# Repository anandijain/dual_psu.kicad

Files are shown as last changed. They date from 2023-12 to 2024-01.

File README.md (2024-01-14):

# diy modular synth in kicad

watch the video series where i build this!

https://www.youtube.com/playlist?list=PL79kqjVnD2ENdJDDSTUD3ZMdZPhVVu8yw

- psu completed, ready to print
- vca (needs to be redone)
- vco 

# todo
- vcf 
- envelope generator

build notes

* for the m2 standoffs i got, use 1/8 in holes and use the m3x12 screws into the acryllic and there is no need to countersink 
* to mount pots to the acryllic, drill 9/32 " holes 
* for 1/4" jack sockets use 3/8" holes

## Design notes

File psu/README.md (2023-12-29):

# psu.kicad

basic +-12v dual power supply from 12vac

designed to be done diy with ferric chloride (thick traces)

## Parts
- big caps https://www.amazon.com/dp/B08KTLQLVK
- -12v regulator https://www.digikey.com/en/products/detail/stmicroelectronics/L7912CV/585997
- +12v regulator https://www.digikey.com/en/products/detail/stmicroelectronics/L7812CV/585973
- diodes https://www.amazon.com/gp/product/B07Q5FZR7X
- small caps https://www.amazon.com/gp/product/B094HRK8QX/
- copper boards https://www.amazon.com/dp/B01MCVLDDZ



00:00:00 intro/materials
00:07:30 buffing board
00:10:00 tracing 
00:26:30 etching
00:42:30 rinse
01:01:00 how to not dremel
01:22:00 drilling
01:39:55 soldering

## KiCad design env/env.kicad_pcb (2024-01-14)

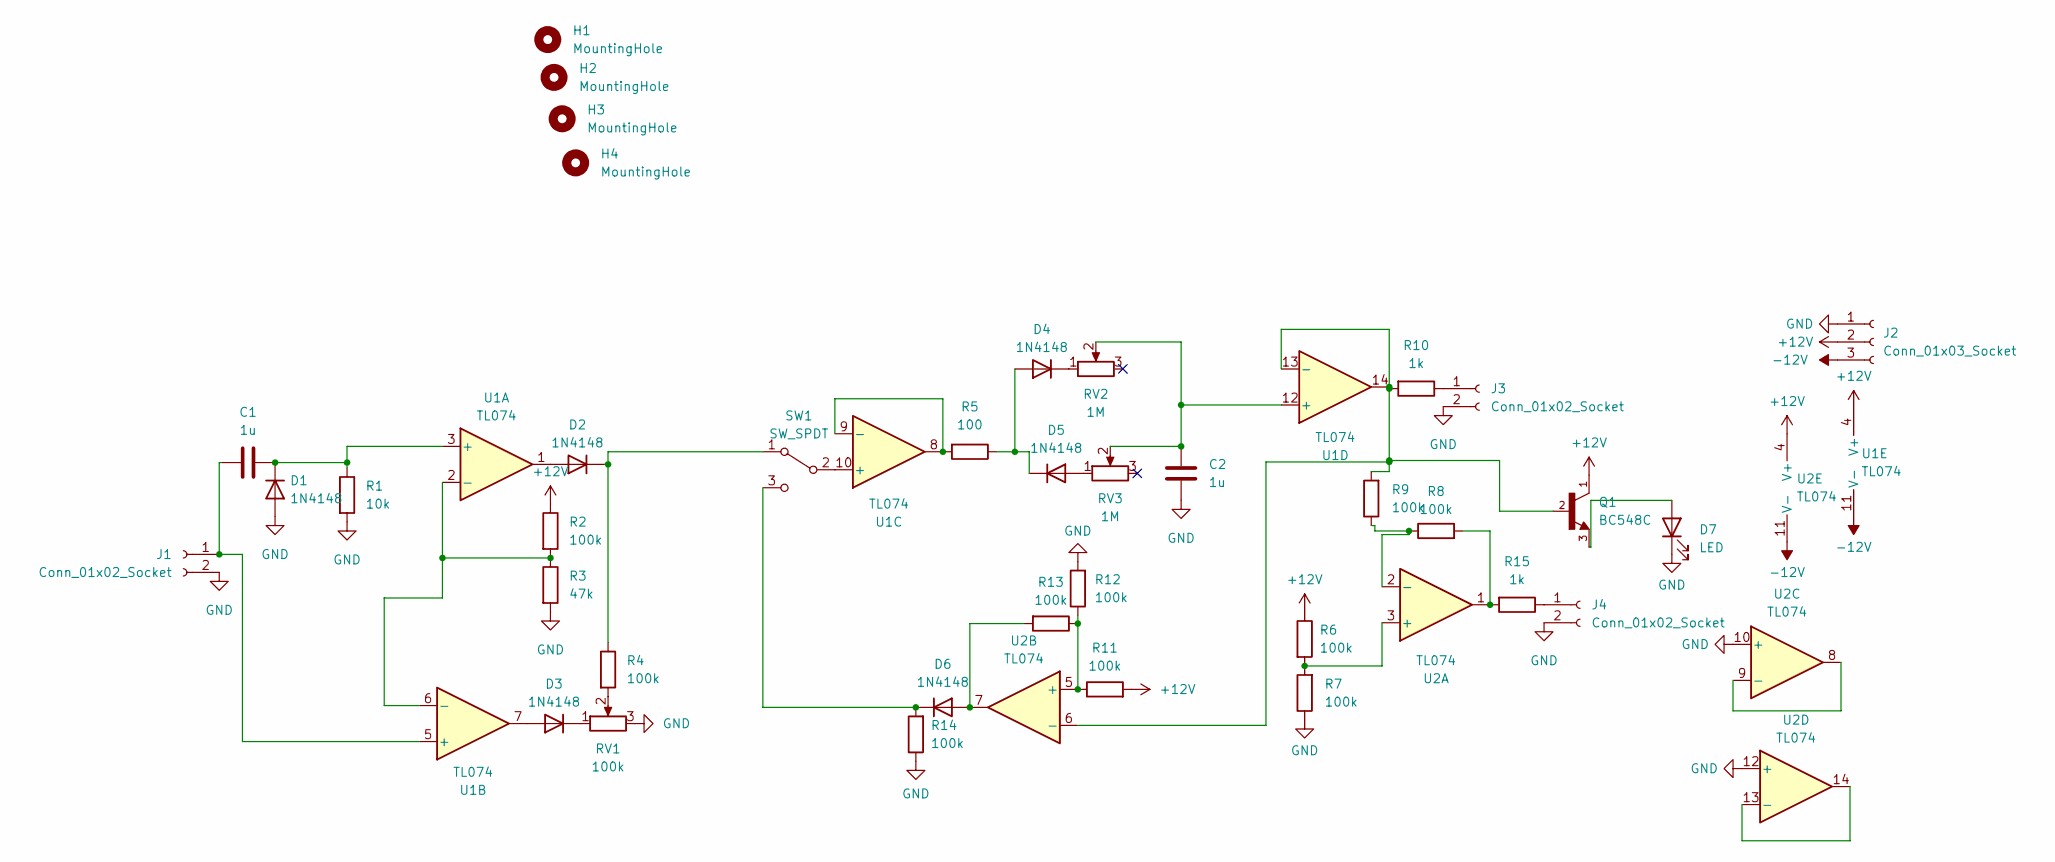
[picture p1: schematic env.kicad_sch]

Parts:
C1, C2: 1u; my_tht_cap
D1, D2, D3, D4, D5, D6: 1N4148; my_tht_diode
D7: LED; LED_D3.0mm
H1, H2, H3, H4: MountingHole; MountingHole_2.1mm
J1, J3, J4: Conn_01x02_Socket; my_really_cool_2pin
J2: Conn_01x03_Socket; my_really_cool_3pin
Q1: BC548C; my_bc548
R1: 10k; my_tht_r
R2, R4, R6, R7, R8, R9, R11, R12, R13, R14: 100k; my_tht_r
R3: 47k; my_tht_r
R5: 100; my_tht_r
R10, R15: 1k; my_tht_r
RV1: 100k; my_really_cool_3pin
RV2, RV3: 1M; my_really_cool_2pin
SW1: SW_SPDT; my_really_cool_3pin
U1, U2: TL074; my_dip14_no_f_pads

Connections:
+12V: J2.2, Q1.1, R2.1, R6.1, R11.2, U1.4 (V+), U2.4 (V+)
-12V: J2.3, U1.11 (V-), U2.11 (V-)
GND: C2.1, D1.2 (A), D7.1 (K), J1.2, J2.1, J3.2, J4.2, R1.2, R3.2, R7.1, R12.2, R14.1, RV1.3, U2.10 (+), U2.12 (+)
unnamed: C1.2, D1.1 (K), R1.1, U1.3 (+)
unnamed: D2.2 (A), U1.1
unnamed: D2.1 (K), R4.1, SW1.1 (A)
unnamed: D3.2 (A), U1.7
unnamed: D3.1 (K), RV1.1
unnamed: D4.2 (A), D5.1 (K), R5.1
unnamed: D4.1 (K), RV2.1
unnamed: D5.2 (A), RV3.1
unnamed: D6.2 (A), R13.2, U2.7
unnamed: D6.1 (K), R14.2, SW1.3 (C)
unnamed: D7.2 (A), Q1.3
unnamed: C1.1, J1.1, U1.5 (+)
unnamed: J3.1, R10.1
unnamed: J4.1, R15.1
unnamed: R4.2, RV1.2
unnamed: R8.2, R15.2, U2.1
unnamed: SW1.2 (B), U1.10 (+)
unnamed: R2.2, R3.1, U1.2 (-), U1.6 (-)
unnamed: R5.2, U1.8, U1.9 (-)
unnamed: C2.2, RV2.2, RV3.2, U1.12 (+)
unnamed: Q1.2, R9.2, R10.2, U1.13 (-), U1.14, U2.6 (-)
unnamed: R6.2, R7.2, U2.3 (+)
unnamed: R8.1, R9.1, U2.2 (-)
unnamed: R11.1, R12.1, R13.1, U2.5 (+)
unnamed: U2.8, U2.9 (-)
unnamed: U2.13 (-), U2.14

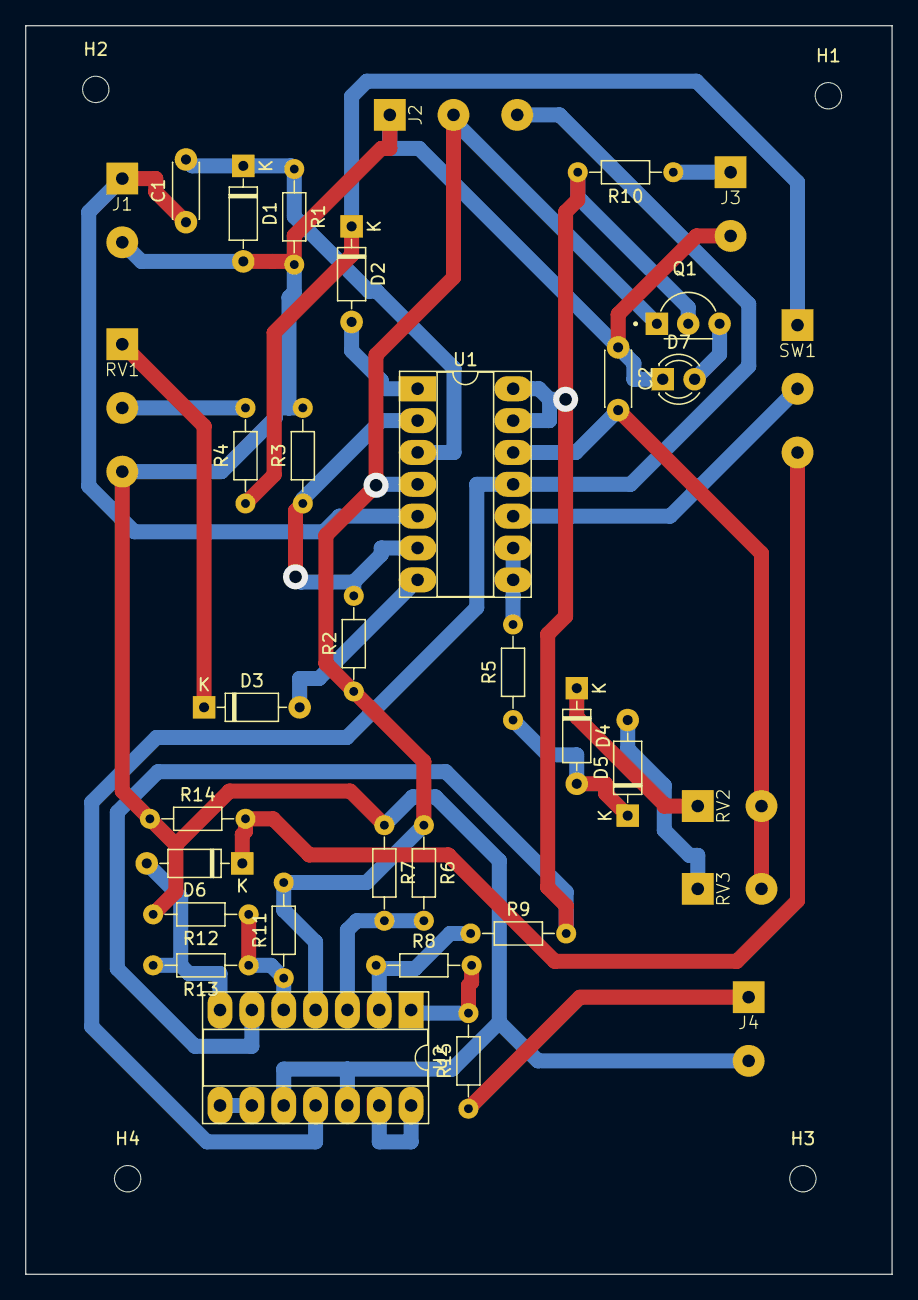
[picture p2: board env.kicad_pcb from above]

Board: 2 copper layers, 69.1 x 99.6 mm, 39 parts (0 on the bottom side), 29 nets.

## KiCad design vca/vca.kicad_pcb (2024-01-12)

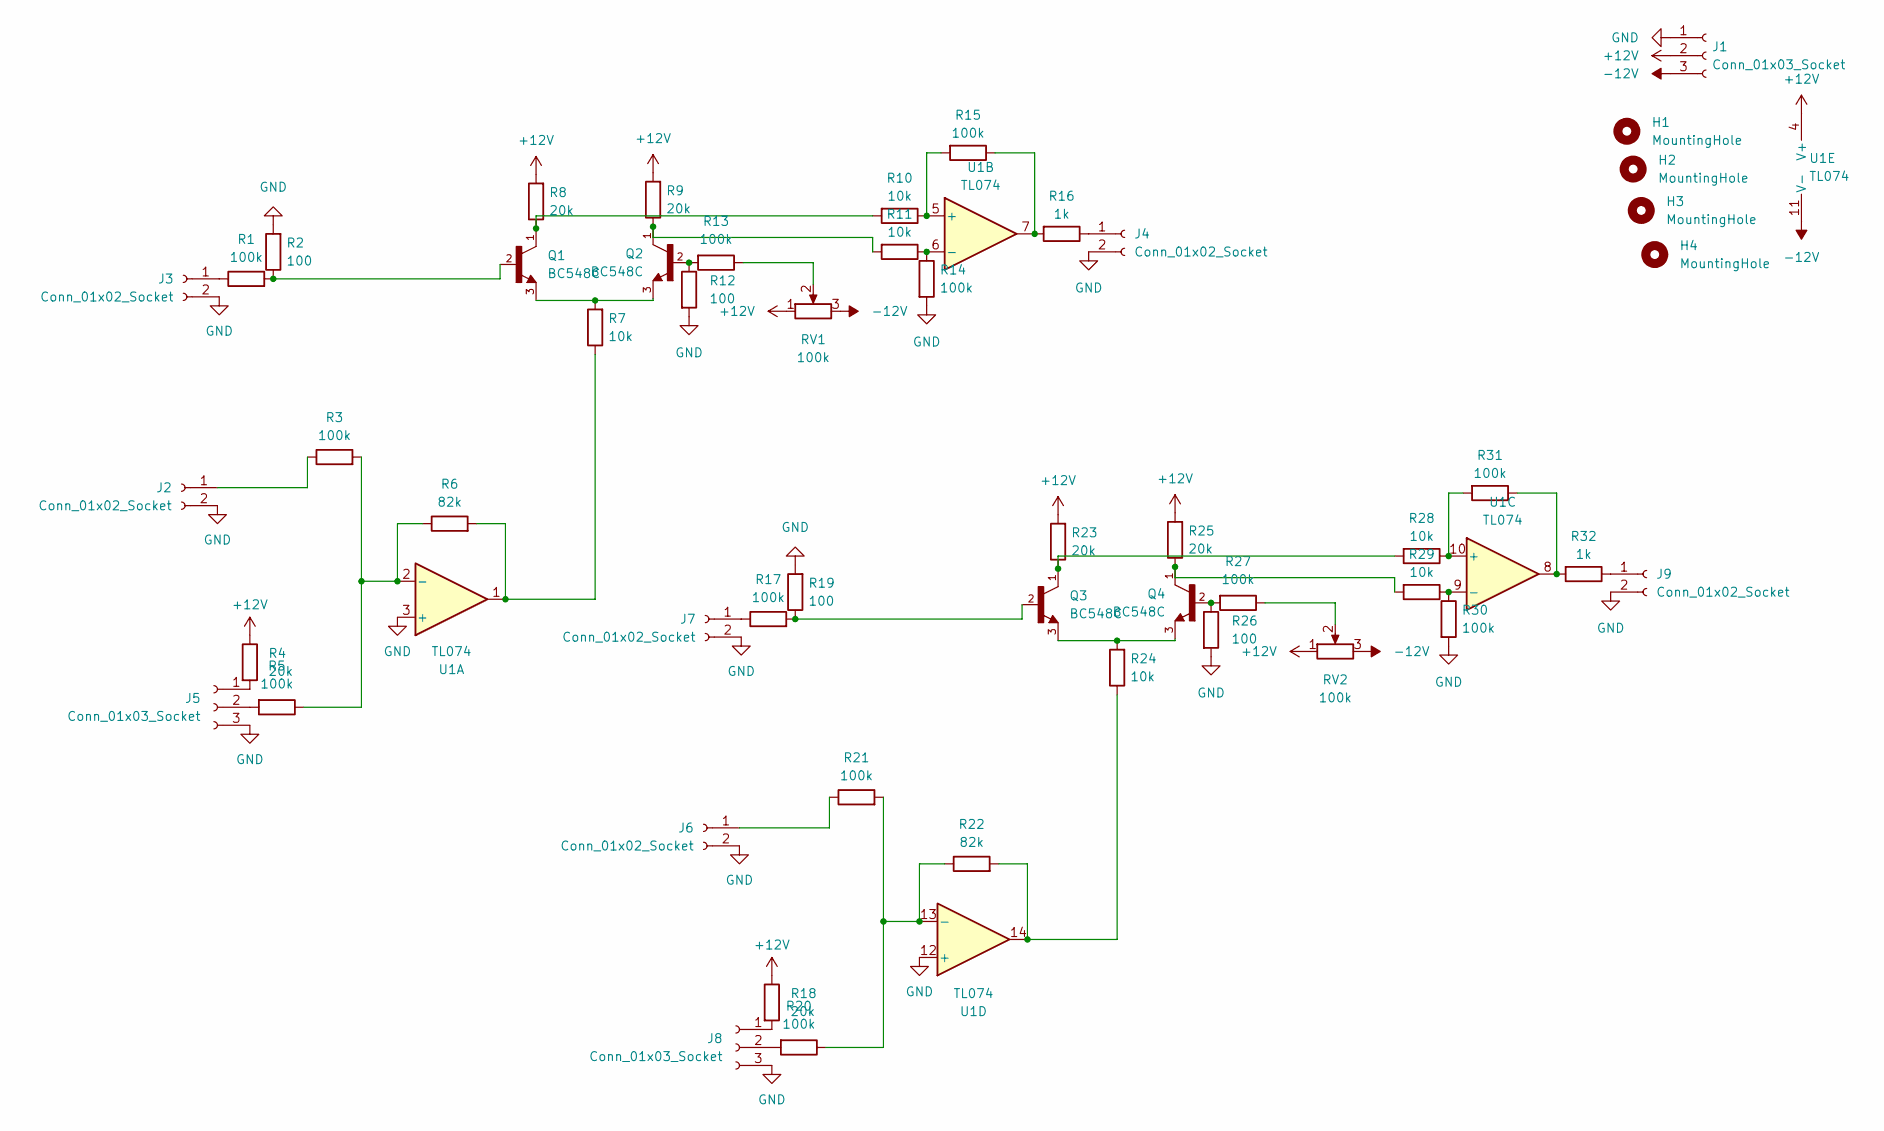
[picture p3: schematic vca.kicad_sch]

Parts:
H1, H2, H3, H4: MountingHole; MountingHole_2.1mm
J1, J5, J8: Conn_01x03_Socket; my_really_cool_3pin
J2, J3, J4, J6, J7, J9: Conn_01x02_Socket; my_really_cool_2pin
Q1, Q2, Q3, Q4: BC548C; my_bc548
R1, R3, R5, R13, R14, R15, R17, R20, R21, R27, R30, R31: 100k; my_tht_r
R2, R12, R19, R26: 100; my_tht_r
R4, R8, R9, R18, R23, R25: 20k; my_tht_r
R6, R22: 82k; my_tht_r
R7, R10, R11, R24, R28, R29: 10k; my_tht_r
R16, R32: 1k; my_tht_r
RV1, RV2: 100k; my_trimmer
U1: TL074; my_dip14_no_f_pads

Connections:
+12V: J1.2, R4.1, R8.2, R9.2, R18.1, R23.2, R25.2, RV1.1, RV2.1, U1.4 (V+)
-12V: J1.3, RV1.3, RV2.3, U1.11 (V-)
GND: J1.1, J2.2, J3.2, J4.2, J5.3, J6.2, J7.2, J8.3, J9.2, R2.2, R12.2, R14.2, R19.2, R26.2, R30.2, U1.3 (+), U1.12 (+)
unnamed: J2.1, R3.1
unnamed: J3.1, R1.1
unnamed: J4.1, R16.1
unnamed: J5.1, R4.2
unnamed: J5.2, R5.2
unnamed: J6.1, R21.1
unnamed: J7.1, R17.1
unnamed: J8.1, R18.2
unnamed: J8.2, R20.2
unnamed: J9.1, R32.1
unnamed: Q1.1, R8.1, R10.2
unnamed: Q1.2, R1.2, R2.1
unnamed: Q1.3, Q2.3, R7.2
unnamed: Q2.1, R9.1, R11.2
unnamed: Q2.2, R12.1, R13.2
unnamed: Q3.1, R23.1, R28.2
unnamed: Q3.2, R17.2, R19.1
unnamed: Q3.3, Q4.3, R24.2
unnamed: Q4.1, R25.1, R29.2
unnamed: Q4.2, R26.1, R27.2
unnamed: R6.2, R7.1, U1.1
unnamed: R13.1, RV1.2
unnamed: R15.1, R16.2, U1.7
unnamed: R22.2, R24.1, U1.14
unnamed: R27.1, RV2.2
unnamed: R31.1, R32.2, U1.8
unnamed: R3.2, R5.1, R6.1, U1.2 (-)
unnamed: R10.1, R15.2, U1.5 (+)
unnamed: R11.1, R14.1, U1.6 (-)
unnamed: R28.1, R31.2, U1.10 (+)
unnamed: R29.1, R30.1, U1.9 (-)
unnamed: R20.1, R21.2, R22.1, U1.13 (-)

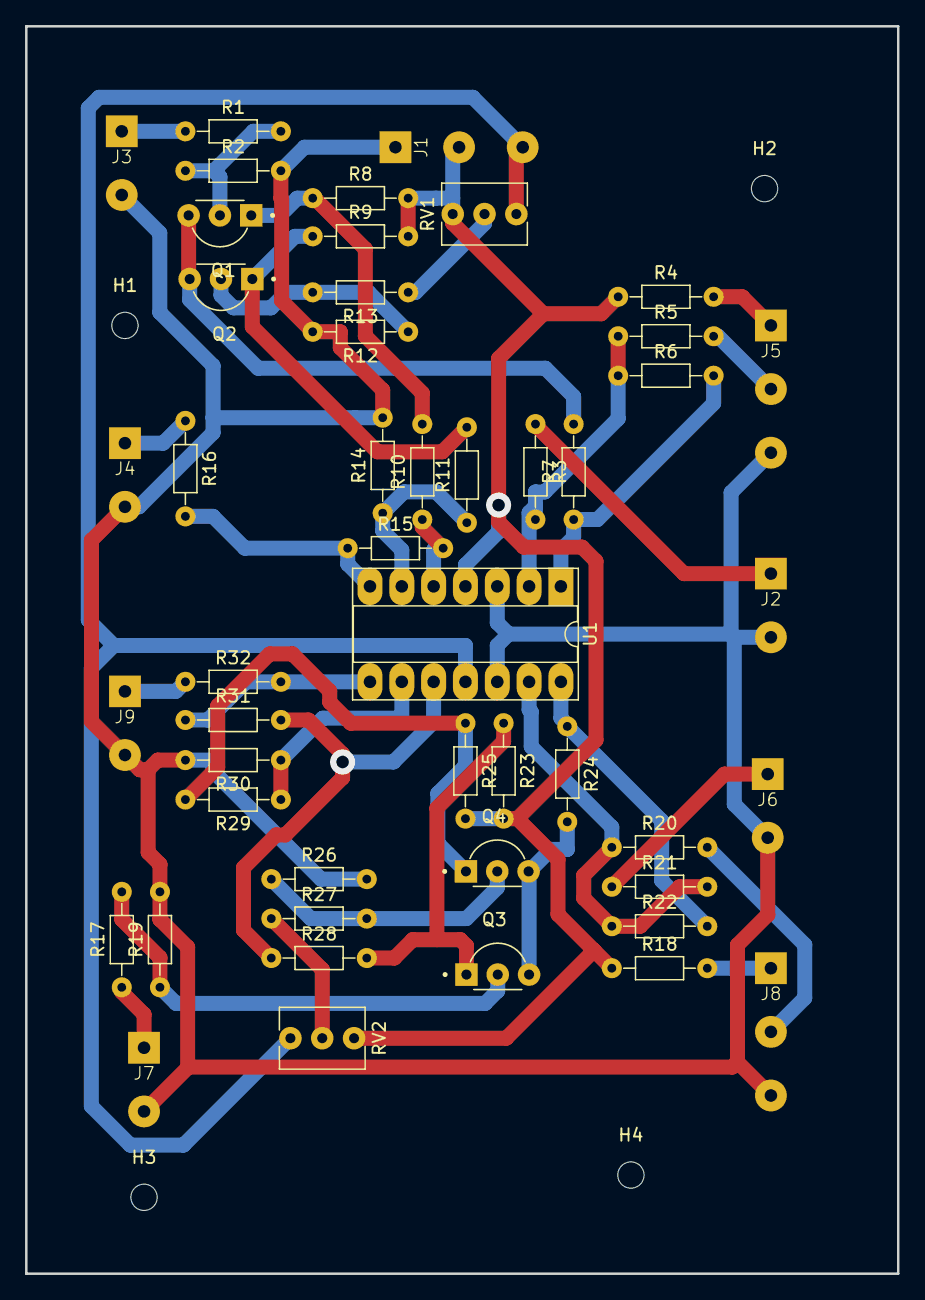
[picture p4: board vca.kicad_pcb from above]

Board: 2 copper layers, 69.6 x 99.6 mm, 52 parts (0 on the bottom side), 35 nets.

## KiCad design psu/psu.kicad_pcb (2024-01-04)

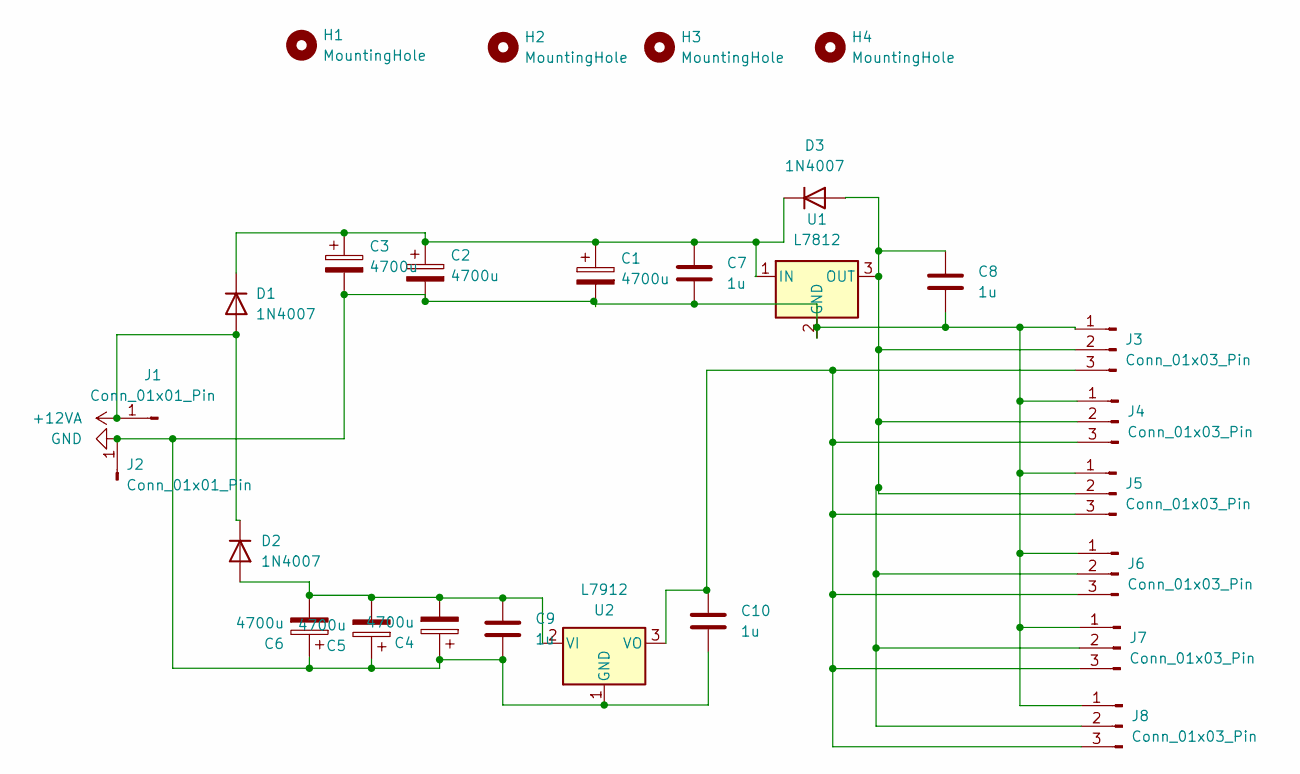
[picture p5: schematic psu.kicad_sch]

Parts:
C1, C2, C3, C4, C5, C6: 4700u; C_Radial_D18.0mm_H35.5mm_P7.50mm
C7, C8, C9, C10: 1u; C_Disc_D4.3mm_W1.9mm_P5.00mm
D1, D2, D3: 1N4007; D_DO-41_SOD81_P10.16mm_Horizontal
H1, H2, H3, H4: MountingHole; MountingHole_2.5mm
J1, J2: Conn_01x01_Pin; PinHeader_1x01_P2.54mm_Vertical
J3, J4, J5, J6, J7, J8: Conn_01x03_Pin; PinHeader_1x03_P2.54mm_Vertical
U1: L7812; TO-220-3_Vertical
U2: L7912; TO-220-3_Vertical

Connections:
+12VA: D1.2 (A), D2.1 (K), J1.1
GND: C1.2, C2.2, C3.2, C4.1, C5.1, C6.1, C7.2, C8.2, C9.2, C10.2, J2.1, J3.1, J4.1, J5.1, J6.1, J7.1, J8.1, U1.2 (GND), U2.1 (GND)
unnamed: C1.1, C2.1, C3.1, C7.1, D1.1 (K), D3.1 (K), U1.1 (IN)
unnamed: C4.2, C5.2, C6.2, C9.1, D2.2 (A), U2.2 (VI)
unnamed: C8.1, D3.2 (A), J3.2, J4.2, J5.2, J6.2, J7.2, J8.2, U1.3 (OUT)
unnamed: C10.1, J3.3, J4.3, J5.3, J6.3, J7.3, J8.3, U2.3 (VO)

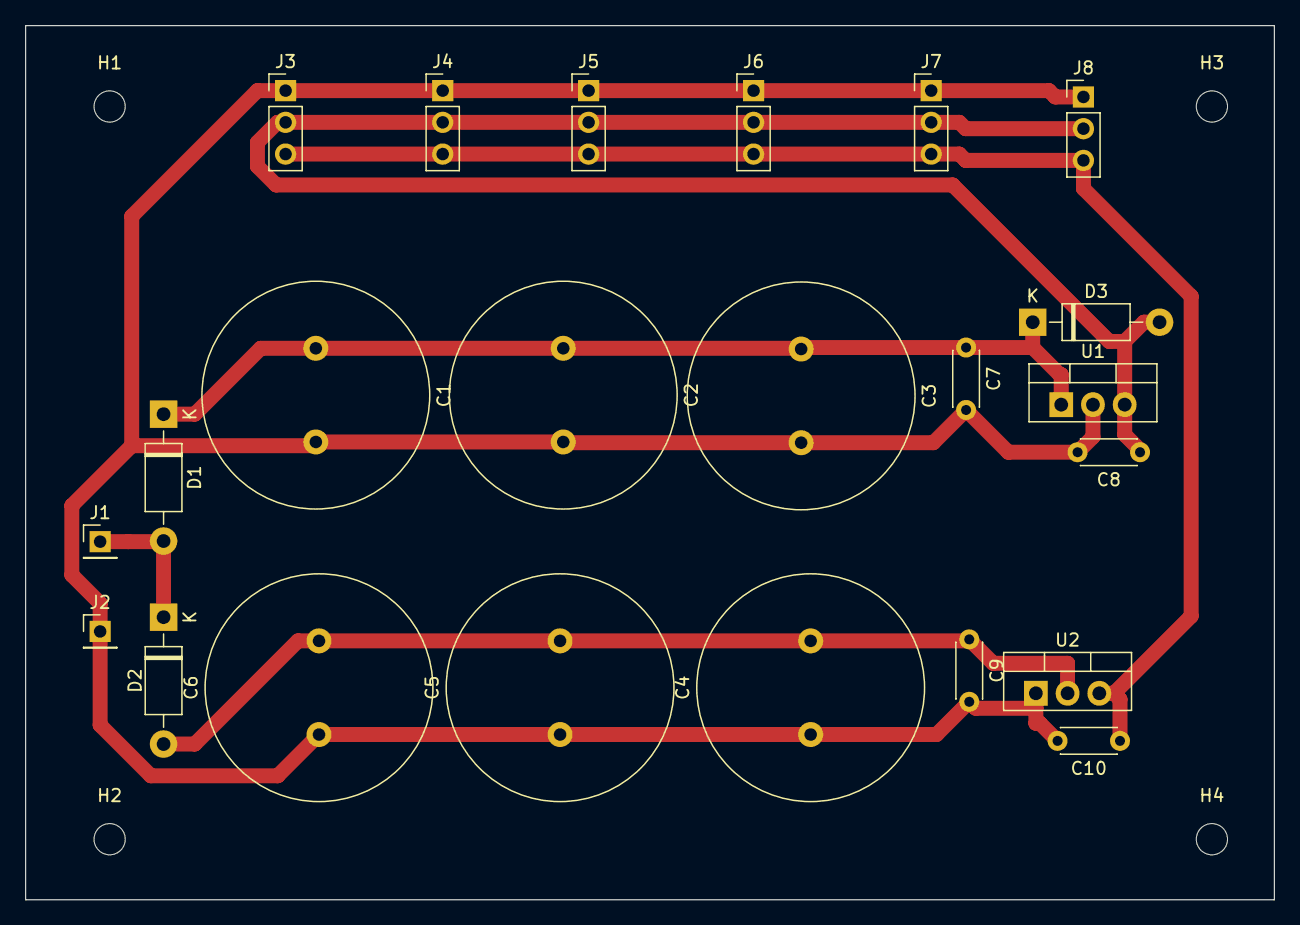
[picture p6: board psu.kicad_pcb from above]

Board: 2 copper layers, 100.0 x 70.0 mm, 27 parts (0 on the bottom side), 6 nets.

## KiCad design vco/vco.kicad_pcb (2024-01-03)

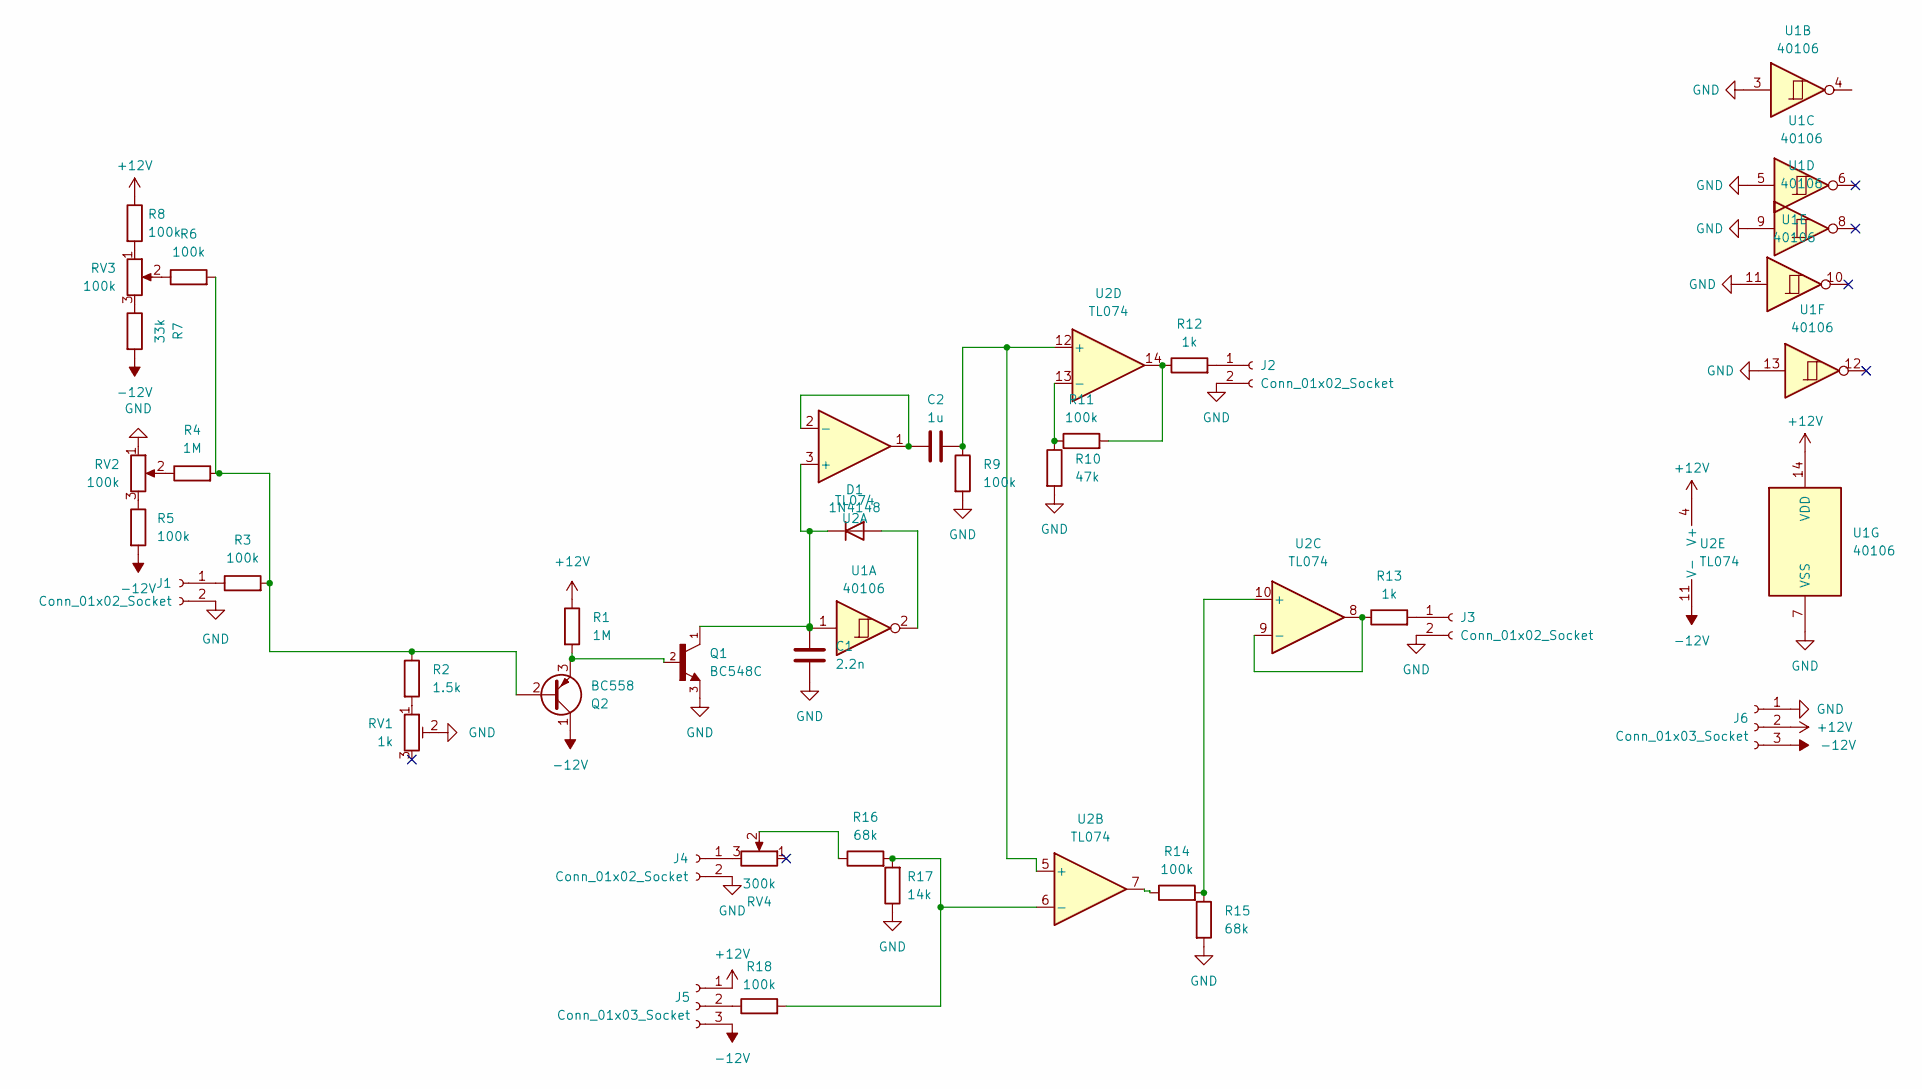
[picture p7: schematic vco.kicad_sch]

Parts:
C1: 2.2n; C_Disc_D7.5mm_W5.0mm_P7.50mm
C2: 1u; C_Disc_D7.5mm_W5.0mm_P7.50mm
D1: 1N4148; D_DO-35_SOD27_P7.62mm_Horizontal
J1, J2, J3, J4: Conn_01x02_Socket; PinSocket_1x02_P2.54mm_Vertical
J5, J6: Conn_01x03_Socket; PinSocket_1x03_P2.54mm_Vertical
Q1: BC548C; TO92250P510H770-3
Q2: BC558; TO-92_Inline_Wide
R1, R4: 1M; R_Axial_DIN0207_L6.3mm_D2.5mm_P10.16mm_Horizontal
R2: 1.5k; R_Axial_DIN0207_L6.3mm_D2.5mm_P10.16mm_Horizontal
R3, R5, R6, R8, R9, R11, R14, R18: 100k; R_Axial_DIN0207_L6.3mm_D2.5mm_P10.16mm_Horizontal
R7: 33k; R_Axial_DIN0207_L6.3mm_D2.5mm_P10.16mm_Horizontal
R10: 47k; R_Axial_DIN0207_L6.3mm_D2.5mm_P10.16mm_Horizontal
R12, R13: 1k; R_Axial_DIN0207_L6.3mm_D2.5mm_P10.16mm_Horizontal
R15, R16: 68k; R_Axial_DIN0207_L6.3mm_D2.5mm_P10.16mm_Horizontal
R17: 14k; R_Axial_DIN0207_L6.3mm_D2.5mm_P10.16mm_Horizontal
RV1: 1k; Potentiometer_Vishay_T73XW_Horizontal
RV2, RV3: 100k; Potentiometer_Runtron_RM-065_Vertical
RV4: 300k; Potentiometer_Runtron_RM-065_Vertical
U1: 40106; DIP-14_W7.62mm
U2: TL074; DIP-14_W7.62mm

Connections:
+12V: J5.1, J6.2, R1.1, R8.1, U1.14 (VDD), U2.4 (V+)
-12V: J5.3, J6.3, Q2.1 (C), R5.2, R7.2, U2.11 (V-)
GND: C1.2, J1.2, J2.2, J3.2, J4.2, J6.1, Q1.3, R9.2, R10.2, R15.2, R17.1, RV1.2, RV2.1, U1.3, U1.5, U1.7 (VSS), U1.9, U1.11, U1.13
unnamed: D1.2 (A), U1.2
unnamed: C1.1, D1.1 (K), Q1.1, U1.1, U2.3 (+)
unnamed: J1.1, R3.1
unnamed: J2.1, R12.2
unnamed: J3.1, R13.2
unnamed: J4.1, RV4.3
unnamed: Q2.2 (B), R2.1, R3.2, R4.2, R6.2
unnamed: Q1.2, Q2.3 (E), R1.2
unnamed: R2.2, RV1.1
unnamed: R4.1, RV2.2
unnamed: R5.1, RV2.3
unnamed: R6.1, RV3.2
unnamed: R7.1, RV3.3
unnamed: R8.2, RV3.1
unnamed: R11.2, R12.1, U2.14
unnamed: R14.1, U2.7
unnamed: R16.1, RV4.2
unnamed: C2.1, U2.1, U2.2 (-)
unnamed: C2.2, R9.1, U2.5 (+), U2.12 (+)
unnamed: R14.2, R15.1, U2.10 (+)
unnamed: R13.1, U2.8, U2.9 (-)
unnamed: R10.1, R11.1, U2.13 (-)

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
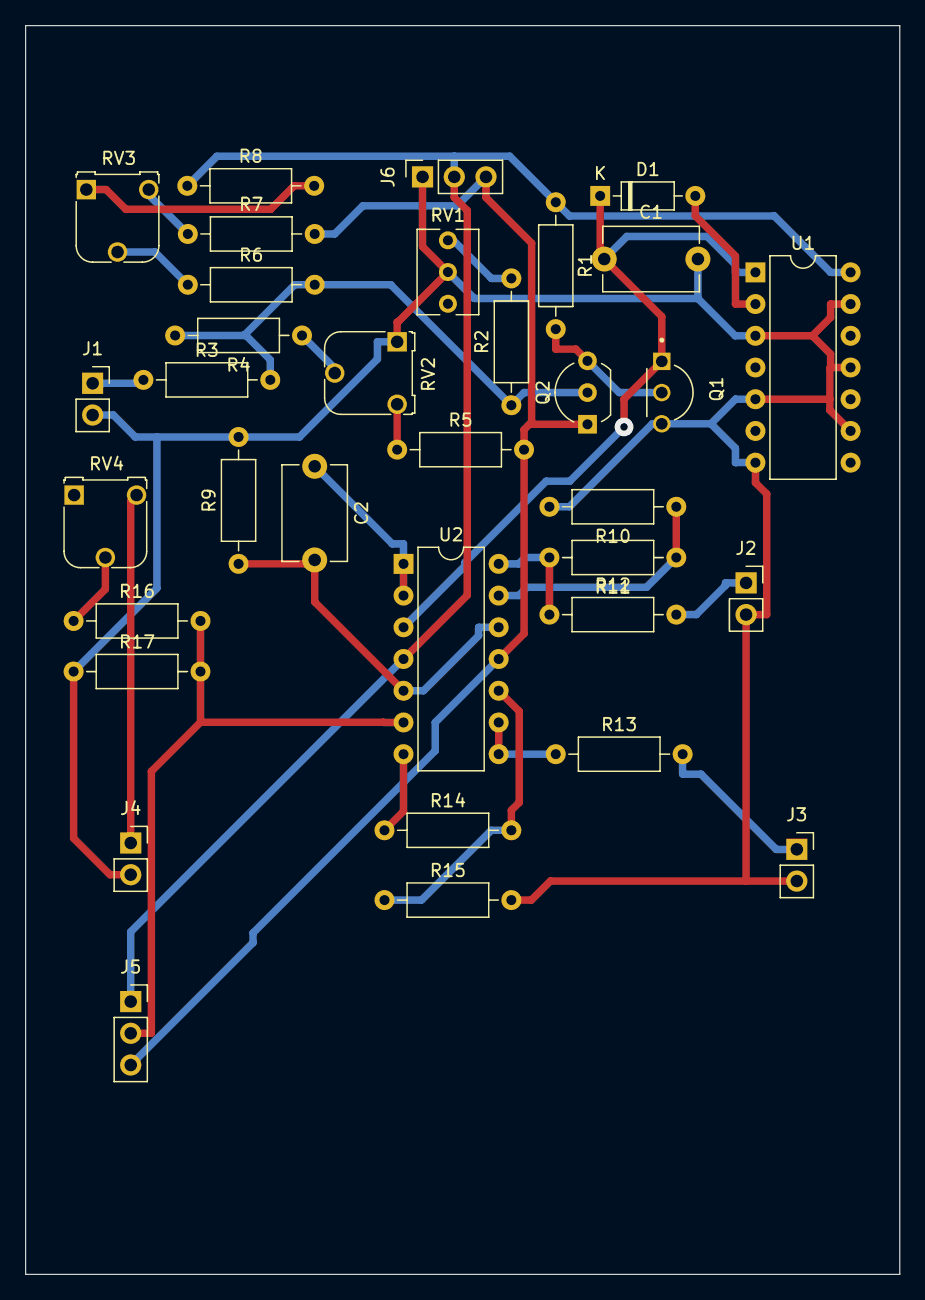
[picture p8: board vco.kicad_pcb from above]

Board: 2 copper layers, 70.0 x 100.0 mm, 34 parts (0 on the bottom side), 26 nets.

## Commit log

2023-12-29 add a vca move things around
    [psu.kicad_pcb, psu.kicad_sch, vca - Copy.kicad_pcb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]
2024-01-01 add vco remove zips
    [vca.kicad_pcb, vco.kicad_pcb, vco.kicad_sch]
2024-01-01 increase track width and clearance + reroute
    [vco.kicad_pcb]
2024-01-01 increase via size
    [vco.kicad_pcb]
2024-01-03 fix missing resistor add link to yt add vco bom
    [vco.kicad_pcb, vco.kicad_sch]
2024-01-04 add psu bom, improve trace width
    [psu.kicad_pcb, psu.kicad_sch]
2024-01-08 add the eg and reroute the vca.
    [env.kicad_pcb, env.kicad_sch, vca - Copy.kicad_pcb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]
2024-01-08 turn vca to dual vca add mounting holes
    [env.kicad_pcb, env.kicad_sch, vca.kicad_pcb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]
2024-01-08 use custom footprints with bigger pads
    [env.kicad_pcb, env.kicad_sch, vca.kicad_pcb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]
2024-01-08 update almost all other footprints to fatty pads
    [env.kicad_sch, vca.kicad_pcb, vca.kicad_sch]
2024-01-12 FRIENDSHIP ENDED WITH PACKAGE_DIP. added a keep-out on F.cu for dip14
    [env.kicad_pcb, env.kicad_sch, vca.kicad_pcb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]
2024-01-14 some notes about front panel construction and some boms
    [env.kicad_pcb, vca.kicad_sch, vcf.kicad_pcb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]
